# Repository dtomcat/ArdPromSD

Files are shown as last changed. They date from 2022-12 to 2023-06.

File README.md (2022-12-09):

# ArduinoProm
                              

This project is based on the work from Ryzee119's ArduinoProm:

>ArduinoProm. An Arduino based Original Xbox EEPROM reader and writer.
>It can be used to recover a HDD key etc. <br><br>
>ArduinoProm is inspired and adapted upon the awesome work by Grimdoomer on PiPROM, now achievable on a <$3 Arduino board.
>See https://github.com/grimdoomer/PiPROM for the Original Raspberry Pi version!
>  
>**Use at your own risk**
>

>The firmware has been written around the Arduino Pro Micro Leonardo (5V/16Mhz). However I would expect it to work on any Arduino with a built in USB >bootloader/Virtual Comport support, and obviously I2C support.
>1. Open `ArduinoProm.ino` in [Arduino IDE](https://www.arduino.cc/en/main/software)
>2. Connect your Arduino to your PC and setup the IDE. An example below <br> Arduino IDE preview
>3. Hit the program button then confirm it compiles and programs successfully.
>
>
>By Ryzee119

MORE WILL BE ADDED LATER TO THIS SPECIFIC PROJECT - dtomcat

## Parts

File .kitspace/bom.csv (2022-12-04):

Reference | Qty | Description | Part Number | Manufacturer | Digikey
IC1 | 1 | IC REG LINEAR 3.3V 800MA SOT223 | LD1117S33TR | STMicroelectronics | 497-1242-1-ND
IC2 | 1 | IC MCU 8BIT 32KB FLASH 44TQFP | ATMEGA32U4-AU | Microchip Technology | ATMEGA32U4-AU-ND
IC3 | 1 | IC BUF NON-INVERT 3.6V 14TSSOP | 74LVC125APW,118 | Nexperia USA Inc. | 1727-3092-1-ND
J1 | 1 | Female Pin Header | PPTC072LFBN-RC | Female Pin Header Generic 2x7 0.1in | S7075-ND
J2 | 1 | MICRO SD PUSH-PUSH, SMT, 1.40MM | MEM2075-00-140-01-A | GCT | 2073-MEM2075-00-140-01-ACT-ND
C1, C2, C6 | 3 | CAP CER 0.1UF 50V Y5V 0805 | CC0805ZRY5V9BB104 | Capacitor Generic | 311-1361-1-ND
C3 | 1 | CAP CER 10UF 6.3V X5R 0603 | JMK107ABJ106MA-T | Capacitor Generic | 587-5869-1-ND
C4, C5 | 2 | CAP CER 22PF 10V C0G/NP0 0805 | 885012007002 | Capacitor Generic | 732-7807-1-ND
C7, C8 | 2 | CAP CER 1UF 25V X7R 0805 | CC0805KFX7R8BB105 | Capacitor Generic | 13-CC0805KFX7R8BB105CT-ND
R1, R4 | 2 | RES 10K OHM 1% 1/4W 0805 | RNCP0805FTD10K0 | Resistor Generic | RNCP0805FTD10K0CT-ND
R2, R3 | 2 | RES 1K OHM 1% 1/4W 0805 | RNCP0805FTD1K00 | Resistor Generic | RNCP0805FTD1K00CT-ND
R5, R6 | 2 | RES 22 OHM 1% 1/4W 0805 | RK73H2ATTD22R0F | Resistor Generic | 2019-RK73H2ATTD22R0FCT-ND
R7, R8, R9, R10 | 4 | RES 3.3K OHM 1% 1/8W 0805 | RC0805FR-103K3L | Resistor Generic | 13-RC0805FR-103K3LCT-ND
GLED | 1 | LED GREEN DIFFUSED 0805 SMD | LG R971-KN-1 | OSRAM Opto (ams OSRAM) | 475-1410-1-ND
RLED | 1 | LED RED DIFFUSED 0805 SMD | LS R976-NR-1 | OSRAM Opto (ams OSRAM) | 475-1278-1-ND
F1 | 1 | PTC RESET FUSE 6V 500MA 0805 | PTS08056V050 | Eaton - Electronics Division | 283-PTS08056V050CT-ND
S2 | 1 | Tactile Switch SPST-NO Top Actuated Surface Mount | TS04-66-70-BK-100-SMT | CUI Devices | 2223-TS04-66-70-BK-100-SMT-ND
Y1 | 1 | CRYSTAL 16.0000MHZ 16PF SMD | TSX-3225 16.0000MF10U-B3 | EPSON | SER4371CT-ND

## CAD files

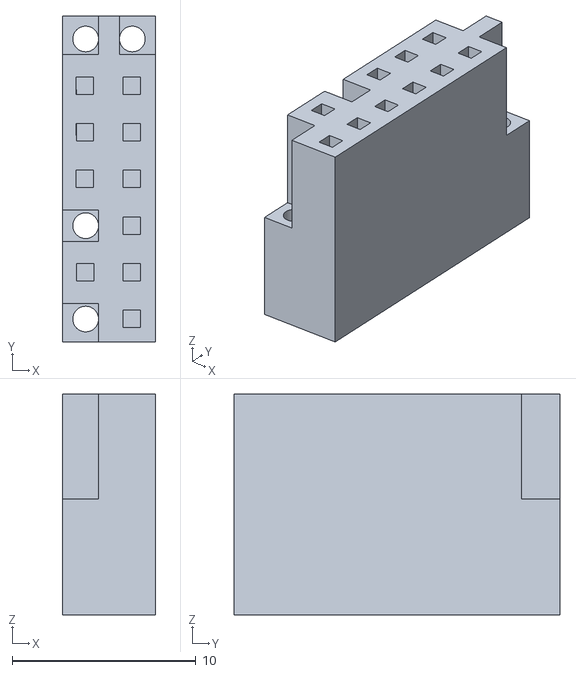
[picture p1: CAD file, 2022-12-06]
3D Prints/Pin2Pogo v5.stl
5.04 x 17.7 x 12.0

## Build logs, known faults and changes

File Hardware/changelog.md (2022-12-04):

1.2 - Fix footprint for J2 (no change electrically) 11/28/2022

1.1 - Fix Ground on Y1

1.0 - Initial Release

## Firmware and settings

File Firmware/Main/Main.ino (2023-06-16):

                                                                            /*
  v1.3a
  https://github.com/dtomcat/ArdPromSD

  ArduinoPromSD is a derivative of the work by Ryzee119 
  (ArduinoProm: https://github.com/dtomcat/ArduinoPromSD)
  This uses an SD card instead of serial communications to 
  backup/write the EEPROM data from the original Xbox.

  ArduinoProm. An Arduino based Original Xbox EEPROM reader and writer.
  It can be used to recover from a corrupt BIOS or recover HDD key etc.

  ArduinoProm is inspired and adapted upon the awesome work by Grimdoomer on PiPROM.
  https://github.com/grimdoomer/PiPROM


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
    You should have received a copy of the GNU General Public License
    along with this program.  If not, see <https://www.gnu.org/licenses/>.
*/

#define XBOX_EEPROM_ADDRESS 0x54
#define XBOX_EEPROM_SIZE    256
#define GLED                4
#define RLED                5
#define BUTT                6 

#include <Wire.h>
#include <SPI.h>
#include <SD.h>

char pbEEPROM[XBOX_EEPROM_SIZE];

void setup() {
  pinMode(GLED, OUTPUT);
  pinMode(RLED, OUTPUT);
  pinMode(BUTT, INPUT);
  digitalWrite(GLED, HIGH); //Green LED on
  digitalWrite(RLED, HIGH); //Red LED on

  Wire.begin();
  Wire.setWireTimeout(30000000);
  //Initialize SD card then check for folder... 
  //if doesn't exist; create it
  if (!SD.begin(10)) {
    delay(100);
    setError();
    while (1);
  }
  if (!SD.exists("epbackup"))
  {
    if (!SD.mkdir("epbackup")) {
      setError();
      while (1);
    }
  }
  //Check for communication with EEPROM
  int returnStatus = -1;
  returnStatus = XboxI2C_DetectEEPROM(XBOX_EEPROM_ADDRESS);
  if (returnStatus == -1) {
    setError();
    while (1);
  }
  //create eeprom.bin and read eeprom from xbox and
  //dump into eeprom.bin
  String filename;
  filename = "epbackup/eeprom.bin";
  int fn = 1;
  while (SD.exists(filename))
  {
    Serial.println(String(fn));  
    filename = "epbackup/eeprom" + String(fn++) + ".bin";
    delay(10);
  }
  File myFile = SD.open(filename, FILE_WRITE);
  // if the file opened okay, write to it:
  if (myFile) {
    returnStatus = XboxI2C_ReadEEPROM(XBOX_EEPROM_ADDRESS, pbEEPROM);
    if (returnStatus != -1) {
      returnStatus = myFile.write(pbEEPROM, XBOX_EEPROM_SIZE);
      if (!returnStatus) {
        setError();
        myFile.close();
        while (1);
      }
    }
    else {
      setError();
      myFile.close();
      while (1);
    }
    // close the file:
    myFile.close();
    setOK();
  }
  else {
    setError();
    while (1);
  }
  //Clear EEPROM data from memory
  memset(pbEEPROM, 0, XBOX_EEPROM_SIZE);
}

void loop() {
  int returnStatus = -1;
  int buttonState = digitalRead(BUTT); //Button Status
  
  //Check if eeprom.bin in writeep folder to write to EEPROM
  //If so, let user know it's ready to write (blinking Green LED)
  //if not, halt program
  if (SD.exists("writeep/eeprom.bin"))
  {
    while (!buttonState) {
      digitalWrite(GLED, !digitalRead(GLED));
      buttonState = digitalRead(BUTT);
      delay(100);
    }
    digitalWrite(GLED, HIGH);

    //Write bin to EEPROM
    memset(pbEEPROM, 0, XBOX_EEPROM_SIZE);
    File myFile = SD.open("writeep/eeprom.bin", FILE_READ);
    returnStatus = myFile.read(pbEEPROM, XBOX_EEPROM_SIZE);
    //Check if file read
    if (returnStatus) {
      returnStatus = XboxI2C_WriteEEPROM(XBOX_EEPROM_ADDRESS, pbEEPROM);
      //Check if write was successful
      if (returnStatus != -1) {
        myFile.close();
        //After successful write... remove file
        SD.remove("writeep/eeprom.bin");
        setOK();
        while (1);
      }
    } else {
      setError();
      myFile.close();
      while(1);
    }
  } else {
    while (1);
  }
}

void setError() {
  digitalWrite(RLED, HIGH); //Red LED on
  digitalWrite(GLED, LOW);  //Green LED off
}

void setOK() {
  digitalWrite(RLED, LOW); //Red LED off
  digitalWrite(GLED, HIGH);  //Green LED on
}

//***********************************************
//**** FOLLOWING CODE WRITTEN BY RYZEE119 *******
//***********************************************


//Read the EEPROM
//bAddress: I2C address of EEPROM
//pbBuffer: Pointer the receiver buffer (256 bytes minimum)
//Returns: -1 on error, 0 on success.
int XboxI2C_ReadEEPROM(char bAddress, char *pbBuffer)
{
  //Some input sanity
  if (bAddress < 0 || bAddress > 128)
    return -1;
  if (pbBuffer == 0)
    return -1;

  memset(pbBuffer, 0, XBOX_EEPROM_SIZE);

  // Read the EEPROM buffer from the chip
  int add = 0;
  Wire.beginTransmission(bAddress);
  Wire.write(add);
  if (Wire.endTransmission(false) == 0) {
    while (add < XBOX_EEPROM_SIZE) {
      Wire.requestFrom(bAddress, 1);
      if (Wire.available()) {
        pbBuffer[add] = Wire.read();
      } else {
        return -1;
      }
      add++;
    }
  } else {
    return -1;
  }

  // Successfully read the EEPROM chip.
  return 0;
}


//Write the EEPROM
//bAddress: I2C address of EEPROM
//pbBuffer: Pointer the transmit data buffer (256 bytes minimum)
//Returns: -1 on error, 0 on success.
int XboxI2C_WriteEEPROM(char bAddress, char *pbBuffer)
{
  char commandBuffer[2];
  int i;

  //Some input sanity
  if (bAddress < 0 || bAddress > 128)
    return -1;
  if (pbBuffer == 0)
    return -1;

  //Loop through the buffer to write.
  for (i = 0; i < XBOX_EEPROM_SIZE; i++)
  {
    Wire.beginTransmission(bAddress);
    // Set the target address and data for the current byte.
    commandBuffer[0] = (char)i;
    commandBuffer[1] = pbBuffer[i];

    // Write the data to the chip.
    Wire.write(commandBuffer, 2);

    if (Wire.endTransmission() != 0) {
      return -1;
    }

    //Wait before writing the next byte.
    delay(10);
  }

  //Successfully wrote the buffer to the EEPROM chip.
  return 0;
}

//Requests an ACK from the EEPROM to detect if it's present
//bAddress: I2C address of EEPROM
//Returns: -1 on error, 0 on success.
int XboxI2C_DetectEEPROM(char bAddress)
{
  Wire.beginTransmission(bAddress);
  if (Wire.endTransmission(true) != 0) {
    return -1;
  }
  //I2C device at specified address detected
  return 0;
}

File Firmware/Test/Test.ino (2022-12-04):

/*
  v1.1aT
  https://github.com/dtomcat/ArdPromSD

  ArduinoPromSD is a derivative of the work by Ryzee119 
  (ArduinoProm: https://github.com/dtomcat/ArduinoPromSD)
  This uses an SD card instead of serial communications to 
  backup/write the EEPROM data from the original Xbox.

  This software is designed to test to ensure board was soldered correctly.


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
    You should have received a copy of the GNU General Public License
    along with this program.  If not, see <https://www.gnu.org/licenses/>.
*/

#define GLED                4
#define RLED                5
#define BUTT                6 

#include <SPI.h>
#include <SD.h>

void setup() {
  pinMode(GLED, OUTPUT);
  pinMode(RLED, OUTPUT);
  pinMode(BUTT, INPUT);
  
  Serial.begin(9600);
  
  while (!Serial) {  // wait for serial port to connect. Needed for native USB port only
    digitalWrite(GLED, !digitalRead(GLED));
    digitalWrite(RLED, !digitalRead(RLED));
    delay(500); 
  }
  
  digitalWrite(GLED, HIGH); //Green LED on
  digitalWrite(RLED, HIGH); //Red LED on
  
  Serial.print("Initializing SD card...");
  //Initialize SD card then check for folder... 
  //if doesn't exist; create it
  if (!SD.begin(10)) {
    delay(100);
    Serial.println("*********************************************");
    Serial.println("SD Card Initialization Failed!");
    Serial.println("*********************************************");
    setError();
    while (1);
  }
  Serial.println("OK");
  Serial.println("Checking for \"test\" folder...");
  if (!SD.exists("test"))
  {
    Serial.println("test doesn't exist...  creating it");
    if (!SD.mkdir("test")) {
      Serial.println("*********************************************");
      Serial.println("Error creating folder");
      Serial.println("*********************************************");
      setError();
      while (1);
    }
  }
  Serial.println("OK");
  //create text.txt and read and write ot it.
  char action;
  if (SD.exists("test/test.txt"))
  {  
    action = O_WRITE | O_TRUNC;
  }else
  {
    action = FILE_WRITE;
  }
  File myFile = SD.open("test/test.txt", action);
  // if the file opened okay, write to it:
  if (myFile) {
    Serial.print("Writing Text to test.txt...");
    int returnStatus = -1;
    returnStatus = myFile.write("testing...");
    if (!returnStatus) {
        Serial.println("*********************************************");
        Serial.println("Error Writing test.txt file.  Please check SD card!");
        Serial.println("*********************************************");
        setError();
        myFile.close();
        while (1);
    }
  }
  else {
      Serial.println("*********************************************");
      Serial.println("Error opening test.txt!");
      Serial.println("*********************************************");
      setError();
      myFile.close();
      while (1);
  }
  // close the file:
  myFile.close();
  Serial.println("Done testing write process...");
  setOK();
  Serial.println("Checking read process...");
  File readFile = SD.open("test/test.txt");
  // if the file opened okay, write to it:
  if (readFile) {
    Serial.print("reading test.txt...");
    Serial.println("CONTENTS:");
    while (readFile.available()) { //execute while file is available
      char letter = readFile.read(); //read next character from file
      Serial.print(letter); //display character
      delay(100);
    }
    Serial.println("");
    Serial.println("*********************************************");
    Serial.println("If \"testing...\" is not displayed under \"CONTENTS:\"... then writing/reading failed");
    Serial.println("*********************************************");
  }
  else {
      Serial.println("*********************************************");
      Serial.println("Error opening test.txt!");
      Serial.println("*********************************************");
      setError();
      readFile.close();
      while (1);
  }
  // close the file:
  readFile.close();
  Serial.println("Done testing read process...");
  setOK();
}

void loop() {
  int returnStatus = -1;
  int buttonState = digitalRead(BUTT); // Button status
  //Check button state and display it
  Serial.println("Press and hold button to test button function!");
  while (!buttonState) {
      digitalWrite(GLED, !digitalRead(GLED));
      buttonState = digitalRead(BUTT);
      delay(100);
    }
  Serial.println("pressed pressed, release button");
  while (buttonState) {
      buttonState = digitalRead(BUTT);
      delay(100);
  }
  Serial.println("*********************************************");
  Serial.println("*********************************************");
  Serial.println("Congratulations, Board Passed!");
  Serial.println("*********************************************");
  Serial.println("*********************************************");
  setOK();
  while(1); 
}

void setError() {
  digitalWrite(RLED, HIGH); //Red LED on
  digitalWrite(GLED, LOW);  //Green LED off
}

void setOK() {
  digitalWrite(RLED, LOW); //Red LED off
  digitalWrite(GLED, HIGH);  //Green LED on
}

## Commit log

2022-10-30 Changes for current project
    Keeping relevant information and giving credit to creators
2022-10-31 Delete ArduinoProm.ino
    Not needed with this project
2022-10-31 Update and rename ArduinoPromSD.ino to ArdPromSD.ino
2022-12-21 Change Timeout to 30secs
    Allows you to plug ArdPromSD into xbox while power is off and gives 30 seconds to turn on the xbox to read the EEPROM before timing out.
2022-12-21 Change timeout to 30 secs
    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
2023-06-16 Update Main.ino
    Fixed write eeprom section
    [Main.ino]

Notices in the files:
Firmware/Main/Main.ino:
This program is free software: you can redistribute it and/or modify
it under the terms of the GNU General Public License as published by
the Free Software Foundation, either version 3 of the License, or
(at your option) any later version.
